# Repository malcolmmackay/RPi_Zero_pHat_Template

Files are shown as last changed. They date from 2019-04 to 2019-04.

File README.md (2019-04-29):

# RFM69HCW-868-S2 Partial HAT for pi Zero
This project includes KiCAD 5.0 CAD files to make a pi Zero HAT with connections from SPI0 device 0 to an RFM69HCW-868-S2 868 MHz transceiver. It was inspired by the OpenAPS project: https://github.com/openaps/openaps.

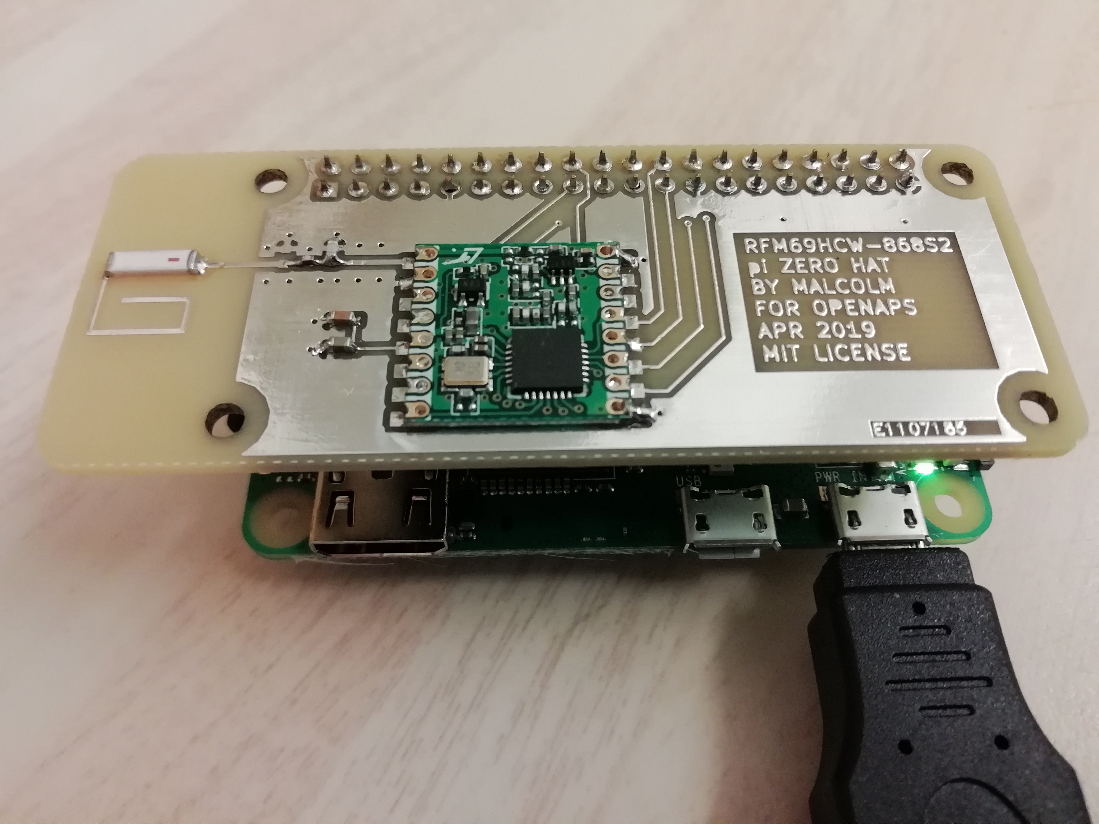
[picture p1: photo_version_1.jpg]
Photo of pHAT connected to pi Zero


This board makes connections from the table on https://openaps.readthedocs.io/en/latest/docs/Gear%20Up/edison.html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 

| Board | Connect | Connect | Connect | Connect | Connect | Connect | Connect | Connect |
| ----- | --- | --- | --- | --- | --- | --- | --- | --- |
| RPi | 3.3V | GND | MOSI | MISO | SCLK | | CEO_N | | 
| RPi PIN | 17 | 25 | 19 | 21 | 23 | 16 | 24 | 18 |
| RFM69HCW | VIN or 3.3V | GND | MOSI | MISO | SCK or CLK | G0 or DIO0 | CS or NSS | RST or RESET |

One of five prototypes made by Eurocircuits for £42 was tested successfully with OpenAPS after following instructions to switch to the development branch.

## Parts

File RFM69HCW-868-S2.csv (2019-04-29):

Reference | Quantity | Value | Footprint | Datasheet | MANF | MANF# | SUPPLIER | SUPPLIER#
AE1 | 1 | 0868AT43A0020E | footprints:0868AT43A0020E | http://www.farnell.com/datasheets/2280483.pdf | JOHANSON | 1885493 | FARNELL | 1885493
C1 | 1 | 3P9 | Capacitors_SMD:C_0603 | http://www.farnell.com/datasheets/1731432.pdf | JOHANSON | 251R14S3R9CV4T | FARNELL | 1885381
C2 | 1 | 0P3 | Capacitors_SMD:C_0603 | http://www.farnell.com/datasheets/1731432.pdf | JOHANSON | 251R14S0R3AV4T | FARNELL | 1885351
C3 | 1 | 100N | Capacitors_SMD:C_0603 | http://www.farnell.com/datasheets/2244871.pdf | VISHAY | VJ0603Y104KXACW1BC | FARNELL | 2407338
C4 | 1 | 1U | Capacitors_SMD:C_0603 | http://www.farnell.com/datasheets/2237828.pdf | AVX | 0603YD105MAT2A | FARNELL | 2332677
J2 | 1 | RPi_GPIO | Connector_PinHeader_2.54mm:PinHeader_2x20_P2.54mm_Vertical |  | WURTH | 61304021821 | FARNELL | 2827916
L1 | 1 | 18N | Resistors_SMD:R_0402 | http://www.farnell.com/datasheets/2372621.pdf | JOHANSON | L-07C18NJV6T | FARNELL | 1865775
U1 | 1 | RFM69HCW | RF:RFM69HCW-XXXS2 | https://www.hoperf.com/data/upload/portal/20181127/5bfcb8284d838.pdf | HOPERF | RFM69HCW-868-S2 | MARITEX | RFM69HCW-868S2

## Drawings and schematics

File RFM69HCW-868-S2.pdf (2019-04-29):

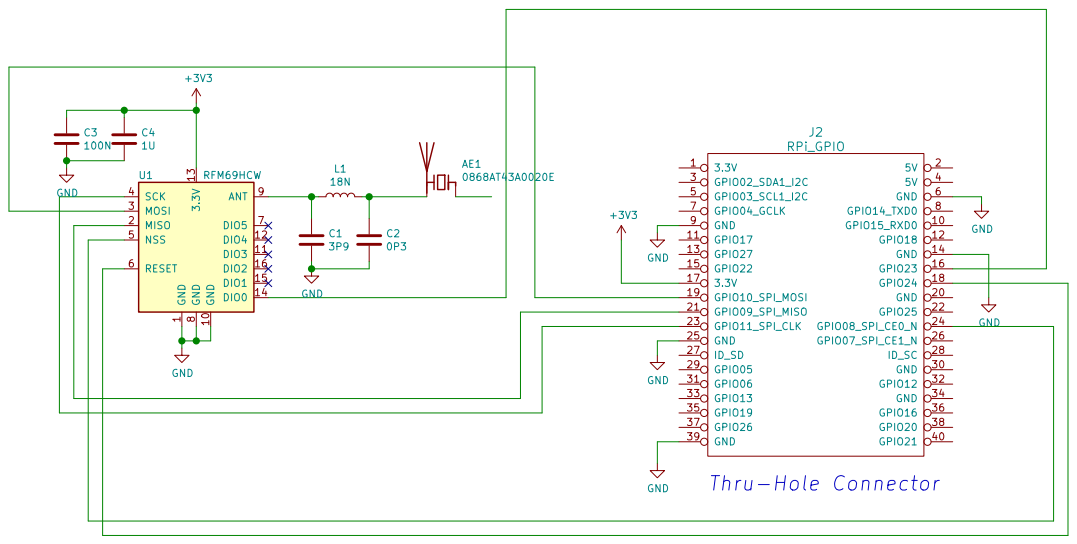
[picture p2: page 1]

1 GND 10 DIO3 11 DIO4 12 3.3V 13 DIO0 14 DIO1 15 DIO2 16 MISO 2 MOSI 3 SCK 4 NSS 5 RESET 6 DIO5 7 GND

File: RFM69HCW-868-S2.sch Sheet: / MM Electronics MIT Licensed Open Source Hardware

Id: 1/1 Title: RFM69HCW-868-S2 partial HAT for pi Zero

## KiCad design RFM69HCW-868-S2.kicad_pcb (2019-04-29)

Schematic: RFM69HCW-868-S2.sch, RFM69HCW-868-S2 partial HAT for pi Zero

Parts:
AE1: 0868AT43A0020E
C1: 3P9; C_0603
C2: 0P3; C_0603
C3: 100N; C_0603
C4: 1U; C_0603
J2: RPi_GPIO; PinHeader_2x20_P2.54mm_Vertical
L1: 18N; R_0402
U1: RFM69HCW; RFM69HCW-XXXS2

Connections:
+3V3: C3.1, C4.1, J2.17, U1.13 (3.3V)
GND: C1.2, C2.2, C3.2, C4.2, J2.6, J2.9, J2.14, J2.25, J2.39, U1.1 (GND), U1.8 (GND), U1.10 (GND)
unnamed: AE1.2, C2.1, L1.2
unnamed: C1.1, L1.1, U1.9 (ANT)
unnamed: J2.16, U1.14 (DIO0)
unnamed: J2.18, U1.6 (RESET)
unnamed: J2.19, U1.3 (MOSI)
unnamed: J2.21, U1.2 (MISO)
unnamed: J2.23, U1.4 (SCK)
unnamed: J2.24, U1.5 (NSS)

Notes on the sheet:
Thru-Hole Connector

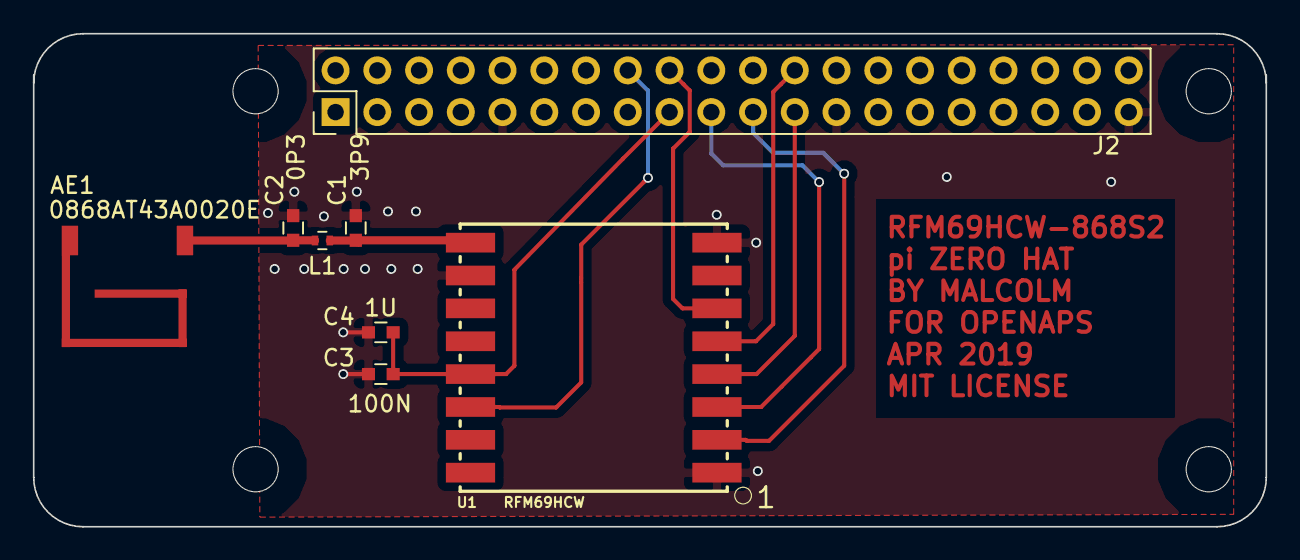
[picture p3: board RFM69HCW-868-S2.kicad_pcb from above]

Board: 2 copper layers, 75.0 x 30.0 mm, 8 parts (0 on the bottom side), 10 nets.

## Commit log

2019-04-29 PCB sent out for manufacture.
    [RPi_Zero_pHat_Template.kicad_pcb, RPi_Zero_pHat_Template.sch]
2019-04-29 Added Gerber files and improved documentation
    [RFM69HCW-868-S2-B.Cu.gbr, RFM69HCW-868-S2-Cmts.User.gbr, RFM69HCW-868-S2-Dwgs.User.gbr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]
2019-04-29 Renamed files to match project name
    Improved documentation
    [RFM69HCW-868-S2.csv, RFM69HCW-868-S2.kicad_pcb, RFM69HCW-868-S2.sch]
